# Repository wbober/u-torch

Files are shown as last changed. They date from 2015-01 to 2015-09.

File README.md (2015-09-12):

u-torch
=======
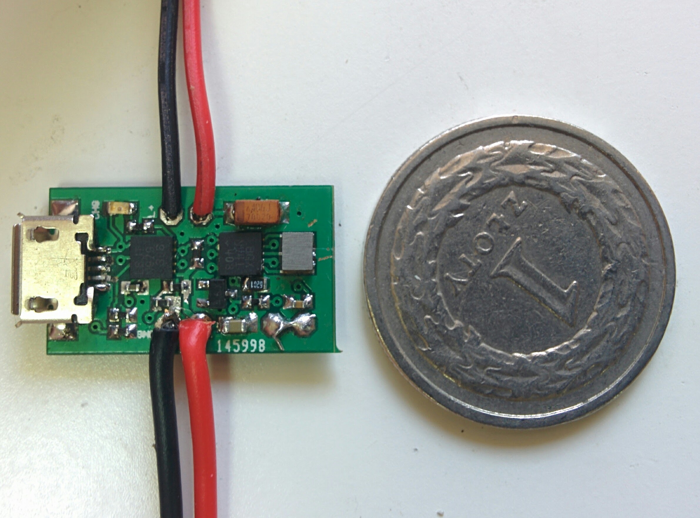
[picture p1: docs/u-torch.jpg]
u-torch


A miniature (2x1cm), high power, LED driver with integrated micro-usb Li-Ion charger.

Features
========
- LTC3454 1A LED driver
- LTC4062 Li-Ion linear charger (from micro-usb)
- Battery cutoff voltage detection
- On/Off switch

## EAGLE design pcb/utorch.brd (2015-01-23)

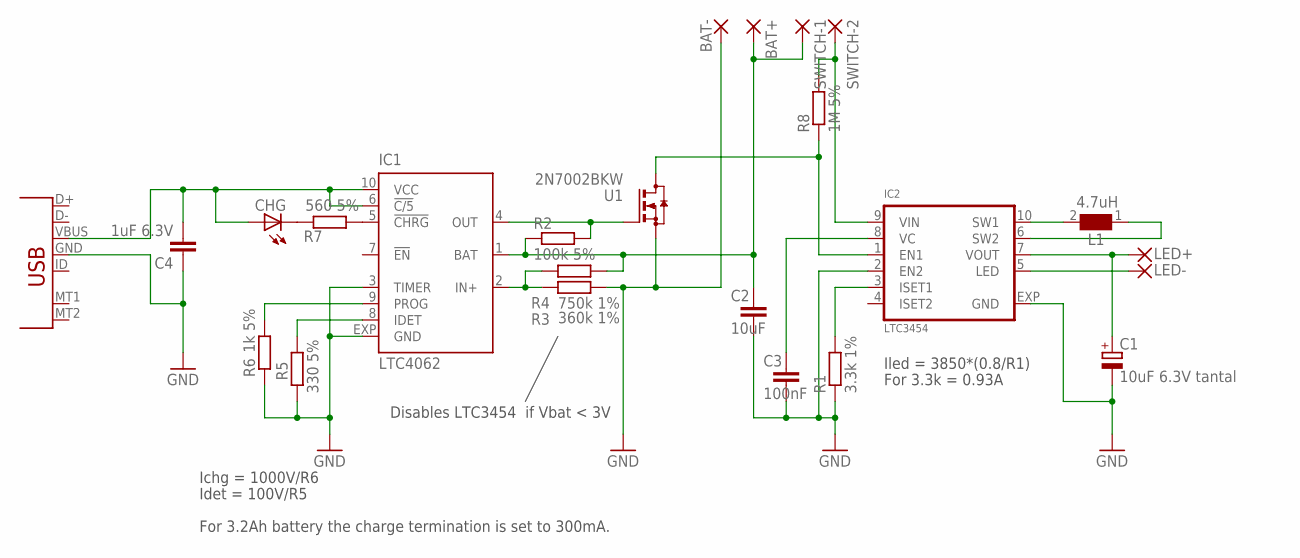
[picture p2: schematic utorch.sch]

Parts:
BAT+: WIREPAD1,6/0,8; 1,6/0,8
BAT-: WIREPAD1,6/0,8; 1,6/0,8
C1: 10uF 6.3V tantal; SMC_A
C2: 10uF; C0603
C3: 100nF; ADL_LIB_001_C0402
C4: 1uF 6.3V; ADL_LIB_001_C0402
CHG: LEDCHIP-LED0603; CHIP-LED0603
IC1: LTC4062; DFN10-3X3
IC2: LTC3454; DFN10-3X3
L1: 4.7uH; WE-MAPI_2510
LED+: WIREPAD1,6/0,8; 1,6/0,8
LED-: WIREPAD1,6/0,8; 1,6/0,8
R1: 3.3k 1%; ADL_LIB_001_R0402
R2: 100k 5%; ADL_LIB_001_R0402
R3: 360k 1%; ADL_LIB_001_R0402
R4: 750k 1%; ADL_LIB_001_R0402
R5: 330 5%; R0402
R6: 1k 5%; R0402
R7: 560 5%; R0402
R8: 1M 5%; ADL_LIB_001_R0402
SWITCH-1, SWITCH-2: WIREPAD1,6/0,8; 1,6/0,8
U1: 2N7002BKW; SOT323
X1: USB-MICROB

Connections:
BAT+: BAT+.1, C2.1, IC1.1 (BAT), R2.1, R4.1, SWITCH-1.1
GND: BAT-.1, C1.-, C2.2, C3.1, C4.1, IC1.3 (TIMER), IC1.EXP (GND), IC2.2 (EN2), IC2.EXP (GND), R1.1, R3.1, R5.1, R6.1, U1.2 (S), X1.GND
unnamed: IC2.10 (SW1), L1.2
unnamed: IC2.6 (SW2), L1.1
unnamed: IC2.5 (LED), LED-.1
unnamed: C1.+, IC2.7 (VOUT), LED+.1
unnamed: IC2.3 (ISET1), R1.2
unnamed: C3.2, IC2.8 (VC)
unnamed: IC2.9 (VIN), R8.2, SWITCH-2.1
unnamed: IC1.8 (IDET), R5.2
unnamed: IC1.9 (PROG), R6.2
unnamed: IC1.4 (OUT), R2.2, U1.1 (G)
unnamed: IC1.2 (IN+), R3.2, R4.2
unnamed: IC1.5 (!CHRG), R7.1
unnamed: CHG.C, R7.2
unnamed: C4.2, CHG.A, IC1.6 (!C/5), IC1.10 (VCC), X1.VBUS
unnamed: IC2.1 (EN1), R8.1, U1.3 (D)

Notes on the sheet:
Ichg = 1000V/R6
Idet = 100V/R5
For 3.2Ah battery the charge termination is set to 300mA.
Iled = 3850*(0.8/R1)
For 3.3k = 0.93A
Disables LTC3454 if Vbat < 3V

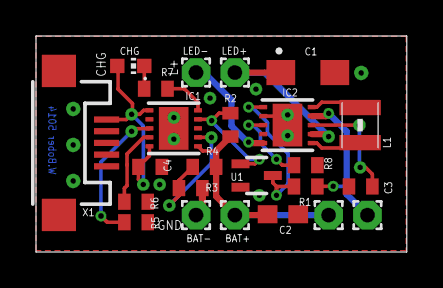
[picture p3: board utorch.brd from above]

Board: 2 copper layers, 20.6 x 12.0 mm, 24 parts (0 on the bottom side), 17 nets.

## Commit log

2014-12-18 PCB finished
    [utorch.brd, utorch.sch]
2014-12-22 Fixed on/off logic
    [utorch.brd, utorch.sch]
2015-01-01 Increased LED traces width to 0.35mm. Added FAB files.
    [utorch.GBL, utorch.GBO, utorch.GBP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]
2015-01-23 Fixed ltc4062 enable pin...
    [utorch.brd, utorch.sch]
2015-09-12 Directory cleanup, added photo, upaded readme.md
    [utorch.GBL, utorch.GBO, utorch.GBP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]

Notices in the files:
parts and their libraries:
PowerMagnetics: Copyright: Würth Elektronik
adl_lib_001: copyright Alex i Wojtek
